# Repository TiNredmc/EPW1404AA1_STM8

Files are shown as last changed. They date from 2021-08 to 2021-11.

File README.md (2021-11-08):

# EPW1404AA1_STM8
EPW1404AA1 running with STM8L151F3 

Buying links
=

[EPW1404AA1](https://www.aliexpress.com/item/1005002238967941.html).  
[Hirose 11 pin 0.3mm connector](https://www.aliexpress.com/item/32849471537.html).  
[PCB @OSHPark](https://oshpark.com/).  

Source Code
=

Dev source code can be found on my [stm8l_sdcc_template repo](https://github.com/TiNredmc/stm8l_sdcc_template/tree/master/code/EPW1404AA1_SSD1316)  
Watch source code can be found on my [stm8l_sdcc_template repo too](https://github.com/TiNredmc/stm8l_sdcc_template/tree/master/code/Fl3xWatchOLED)

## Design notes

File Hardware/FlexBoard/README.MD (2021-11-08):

# WARNING!

This is still in development. I DON'T recommend you to build using this board. Since I haven't done any electrical testing yet.  
Also schematic and board inspection haven't done enough. I might left some error in the design that can kill some precious components like OLED, Driver chip or STM8.

# Notice

I've removed all of the Rev 1 to Rev 3 board. Due to the connection design error. It turns out that connector only accept FPC with copper contact facing down. I need to redesign the board and came up with Rev4

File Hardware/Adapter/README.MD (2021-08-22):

BOM list. 
1. FH35C-11S-0.3SHW x1
2. 2.2uF 25v 0605 x2
3. 1uF 16v 0605 x1
4. 4.7kOhm x2 
5. 1x3 pin header 2.54mm x2

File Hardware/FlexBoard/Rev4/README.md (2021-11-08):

# Rev 4

This is Rev4 shcematic and board. Fixed the connector.

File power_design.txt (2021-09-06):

This is power design for the FlexWatch OLED project. Entire system is powered by 2.7-3.6 battery. 
NOTE : All part that said "in parallel" is the situation that I don't want to buy more passive component, so just use parallel resistor calculation to find out the lower resistance from connecting
multiple Higher resistance Resistor that I already have in parallel.

possible battery choices.
1. LIR1254 (more expensive than LIR2032 since it's not popular).
2. LIR2032 (probably my goto choice).

Vboost for OLED 
1. LTC3459. L = 33uH, R1 = 2M, R2 = x2 470k in parallel to get 11volt boost, Cvin = 1uF, Cvout = 2.2uF to 10uF.
2. LT3494. L = 15uH, R1 = 1.3M (x2 2M in parallel might work), Ccap = .22uF, Cvout = 2.2uF.

STM8L151F3 power.
1. Normal High speed core clock is running at 1MHz, RTC running with 38kHz LSI.
2. Put to sleep in Active halt mode, wake by portB EXTI (4 position mini joy stick + 1 middle button).

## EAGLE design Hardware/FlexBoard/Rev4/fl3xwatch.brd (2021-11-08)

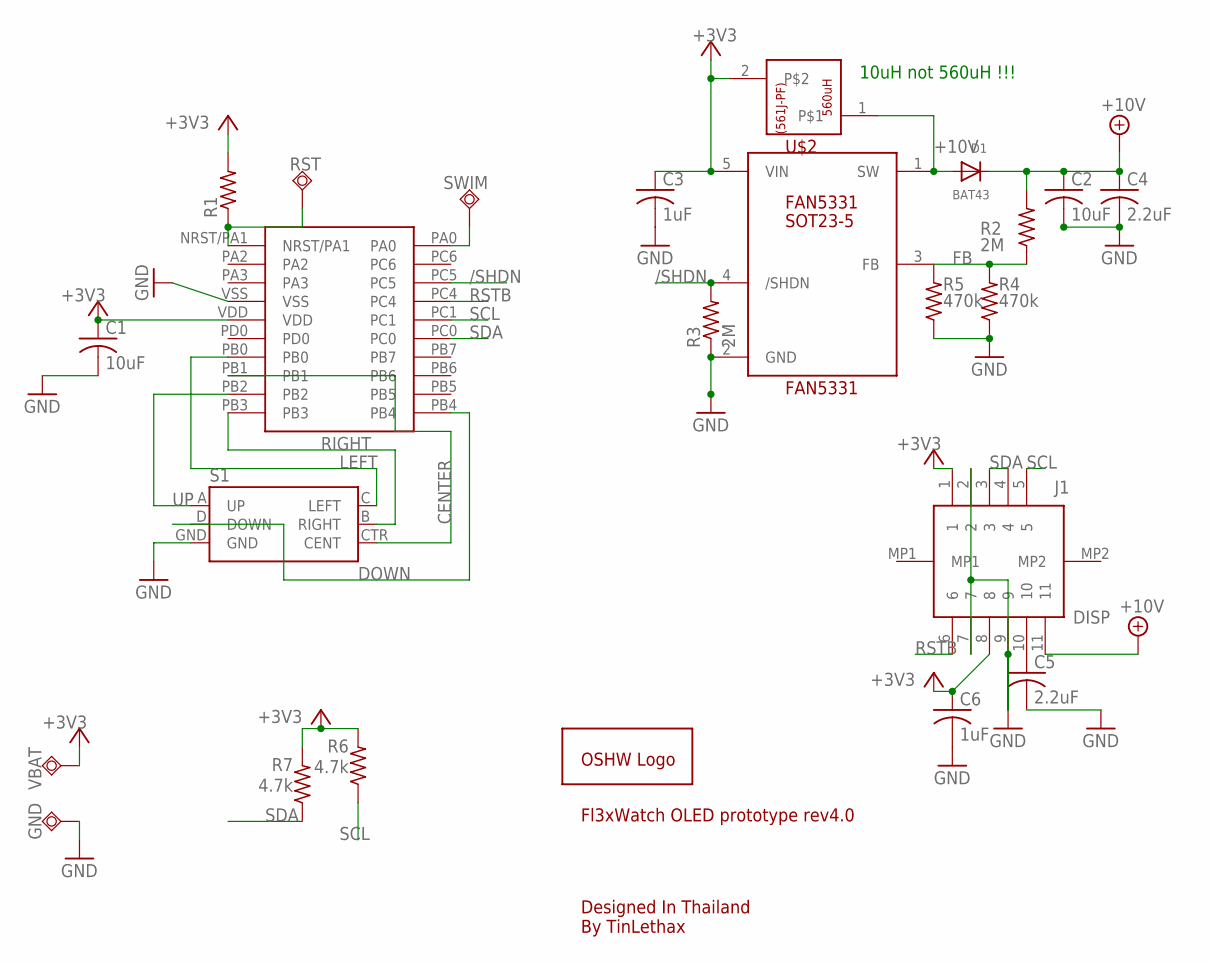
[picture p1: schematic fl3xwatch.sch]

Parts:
C1, C2: 10uF; C0805
C3, C6: 1uF; C0603
C4, C5: 2.2uF; C0603
D1: BAT43; SOD-323F
GND: TPSQTP20SQ; TP20SQ
GOLD_ORB_SM1: OSHWLOGOLOGO5MM; OSHW_5MM
J1: DISP; FH35C11S03SHW50
L1: 10uH; INDC4526X50N
R1: R-US_R0603; R0603
R2, R3: 2M; R0603
R4, R5: 470k; R0805
R6, R7: 4.7k; R0603
RST: TPSQTP15R; TP15R
S1: SPARKFUN-ELECTROMECHANICAL_JOYSTICK_MINI
SWIM: TPSQTP15R; TP15R
U$1: STM8L151F3; UFQFPN-20
U$2: FAN5331; SOT95P280X145-5N
VBAT: TPSQTP20SQ; TP20SQ

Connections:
+3V3: C1.1, C3.1, C6.1, J1.1, J1.8, L1.2, R1.2, R6.2, R7.2, U$1.VDD, U$2.5 (VIN), VBAT.TP
+10V: C2.1, C4.1, D1.C, J1.11, R2.2
/SHDN: R3.2, U$1.PC5, U$2.4 (/SHDN)
CENTER: S1.CTR (CENT), U$1.PB1
DOWN: S1.D (DOWN), U$1.PB4
FB: R2.1, R4.2, R5.2, U$2.3 (FB)
GND: C1.2, C2.2, C3.2, C4.2, C5.2, C6.2, GND.TP, J1.2, J1.7, J1.9, R3.1, R4.1, R5.1, S1.GND, U$1.VSS, U$2.2 (GND)
LEFT: S1.C (LEFT), U$1.PB0
unnamed: R1.1, RST.TP, U$1.NRST/PA1
unnamed: C5.1, J1.10
RIGHT: S1.B (RIGHT), U$1.PB3
RSTB: J1.6, U$1.PC4
SCL: J1.5, R6.1, U$1.PC1
SDA: J1.3, J1.4, R7.1, U$1.PC0
SW: D1.A, L1.1, U$2.1 (SW)
SWIM: SWIM.TP, U$1.PA0
UP: S1.A (UP), U$1.PB2

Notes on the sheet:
10uH not 560uH !!!
Fl3xWatch OLED prototype rev4.0
Designed In Thailand By TinLethax

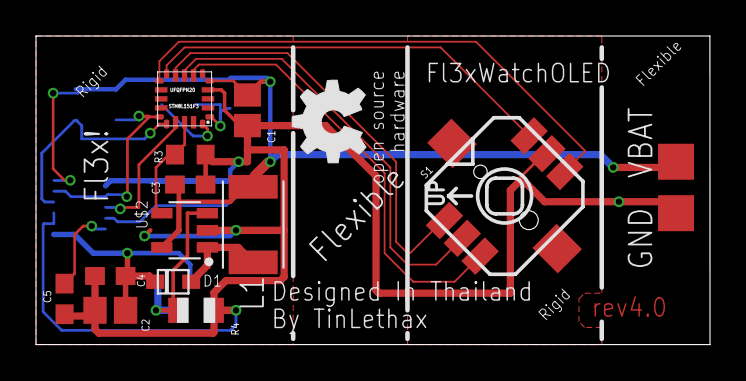
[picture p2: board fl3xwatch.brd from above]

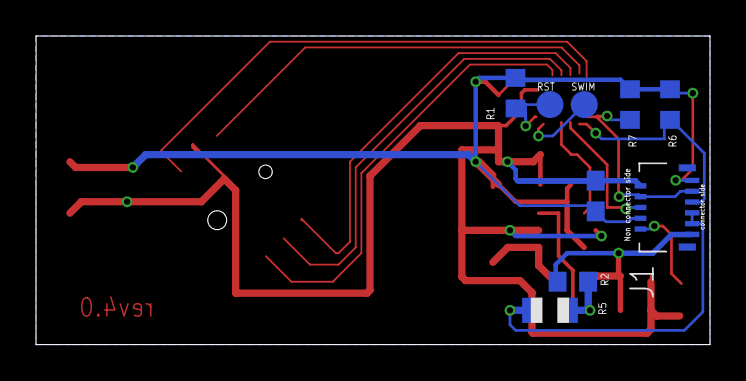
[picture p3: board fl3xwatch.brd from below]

Board: 2 copper layers, 37.4 x 17.1 mm, 24 parts (9 on the bottom side), 17 nets.

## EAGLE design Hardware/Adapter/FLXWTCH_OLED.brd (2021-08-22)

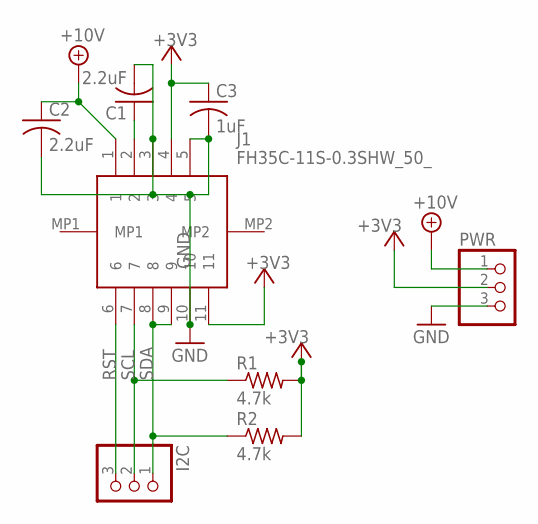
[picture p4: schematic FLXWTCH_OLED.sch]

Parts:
C1, C2: 2.2uF; C0603K
C3: 1uF; C0603K
I2C: PINHD-1X3; 1X03
J1: FH35C-11S-0.3SHW_50_; FH35C11S03SHW50
PWR: PINHD-1X3; 1X03
R1, R2: 4.7k; R0603

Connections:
+3V3: C3.1, J1.4, J1.11, PWR.2, R1.2, R2.2
+10V: C2.1, J1.1, PWR.1
GND: C1.2, C2.2, C3.2, J1.3, J1.5, J1.10, PWR.3
unnamed: C1.1, J1.2
RST: I2C.3, J1.6
SCL: I2C.2, J1.7, R1.1
SDA: I2C.1, J1.8, J1.9, R2.1

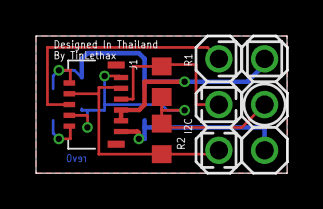
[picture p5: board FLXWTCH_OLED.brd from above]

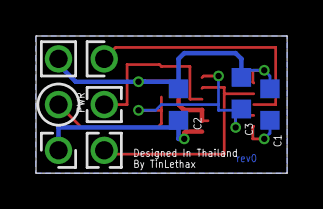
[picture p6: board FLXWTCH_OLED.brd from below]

Board: 2 copper layers, 13.9 x 7.6 mm, 8 parts (3 on the bottom side), 7 nets.

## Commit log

2021-08-22 added BOM list
2021-08-22 Rev0 Schematic and Board
    [FLXWTCH_OLED.brd, FLXWTCH_OLED.sch]
2021-09-01 Added link to buy the PCB at OSHPark
2021-09-06 Added Power design guide.
2021-09-07 added schematic and board file
    [fl3xwatch.brd, fl3xwatch.sch]
2021-09-09 Update PCB link to rev 2.0 and repo links
2021-09-09 added board and sch of rev2.0
    [fl3xwatch.brd, fl3xwatch.sch]
2021-09-09 Update PCB link to rev2.1
2021-09-09 Rev2.1 board
    [fl3xwatch.brd]
2021-09-19 added Rev 2.2 PCB
    [fl3xwatch.brd]
2021-09-26 rev 3 board changelog
2021-09-26 update PCB link to rev3.1
2021-09-28 rev 2.1
    corrected the inductor value. user
    [fl3xwatch.sch]
2021-11-08 removed due to design error.
    [fl3xwatch.brd, fl3xwatch.sch]
2021-11-08 rev4 board and schematic.
    [fl3xwatch.brd, fl3xwatch.sch]
2021-11-08 removed link to PCB, prevent you from my failure.
